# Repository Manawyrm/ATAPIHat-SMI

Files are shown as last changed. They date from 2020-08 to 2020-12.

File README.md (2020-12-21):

ATAPIHat-SMI
=============================

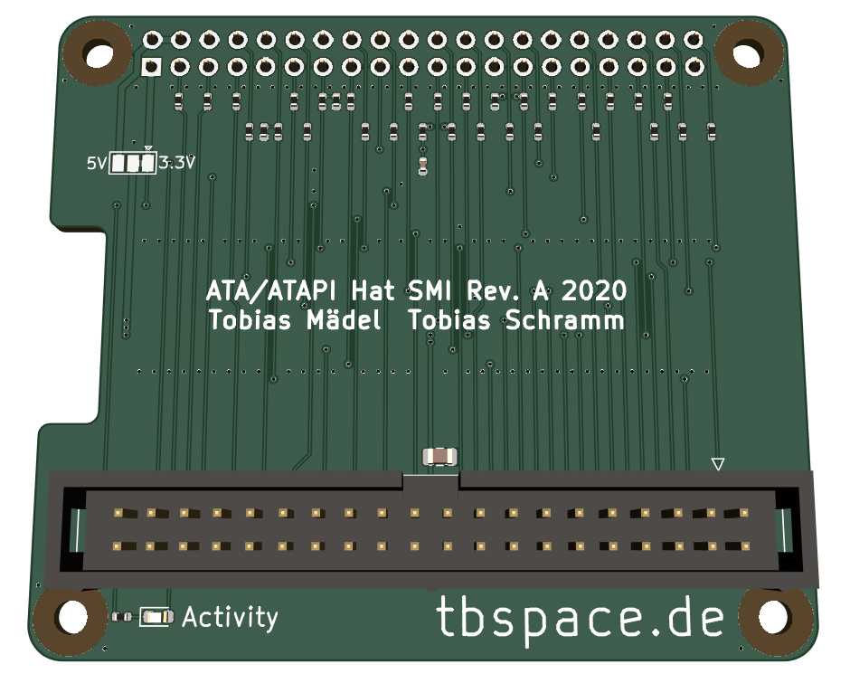
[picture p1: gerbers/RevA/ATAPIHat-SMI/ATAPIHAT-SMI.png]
Adapter PCB


### Overview

This is an experimental adapter PCB for the pata-gpio driver.  
The pinout was chosen deliberately to support faster SMI and BCM2835 register modes,  
which are not yet supported in the kernel driver. 

Rev.A testboards were ordered but not tested yet. **Proceed at your own risk.** 

### Manufacturing
Manufacturing files for [JLCPCBs](https://jlcpcb.com) automatic assembly service can be found at `gerbers/RevA/ATAPIHat-SMI/`.  
5 adapter boards cost ~15$ (incl. components). 

### Additional info 

[Schematic](gerbers/RevA/ATAPIHat-SMI/ATAPIHat-SMI.pdf)  
[Interactive BOM](https://tbspace.de/content/downloads/atapihat-smi-ibom-reva.html)  
[Bitbanged-GPIO Kernel driver](https://github.com/Manawyrm/pata-gpio)  

### Credits
The PCB layout was done by [@Toble_Miner](https://github.com/TobleMiner)! Thanks!

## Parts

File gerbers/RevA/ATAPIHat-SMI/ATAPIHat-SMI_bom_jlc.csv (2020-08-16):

Comment | Designator | Footprint | LCSC Part #
100nF | C1 | C_0402_1005Metric | C1525
22uF | C2 | C_0805_2012Metric | C45783
LED | D1 | LED_0603_1608Metric | C72043
4.7k | R3,R17 | R_0402_1005Metric | C25900
75R | R8,R7,R20 | R_0402_1005Metric | C25133
10k | R16,R18 | R_0402_1005Metric | C25744
5.6k | R19 | R_0402_1005Metric | C25908
22R | R23,R30,R14 | R_0402_1005Metric | C25092
33R | R24,R31,R25,R32,R26,R33,R9,R1,R2,R10,R11,R4,R12,R5,R13,R6,R29,R22,R28,R21,R15,R27 | R_0402_1005Metric | C25105

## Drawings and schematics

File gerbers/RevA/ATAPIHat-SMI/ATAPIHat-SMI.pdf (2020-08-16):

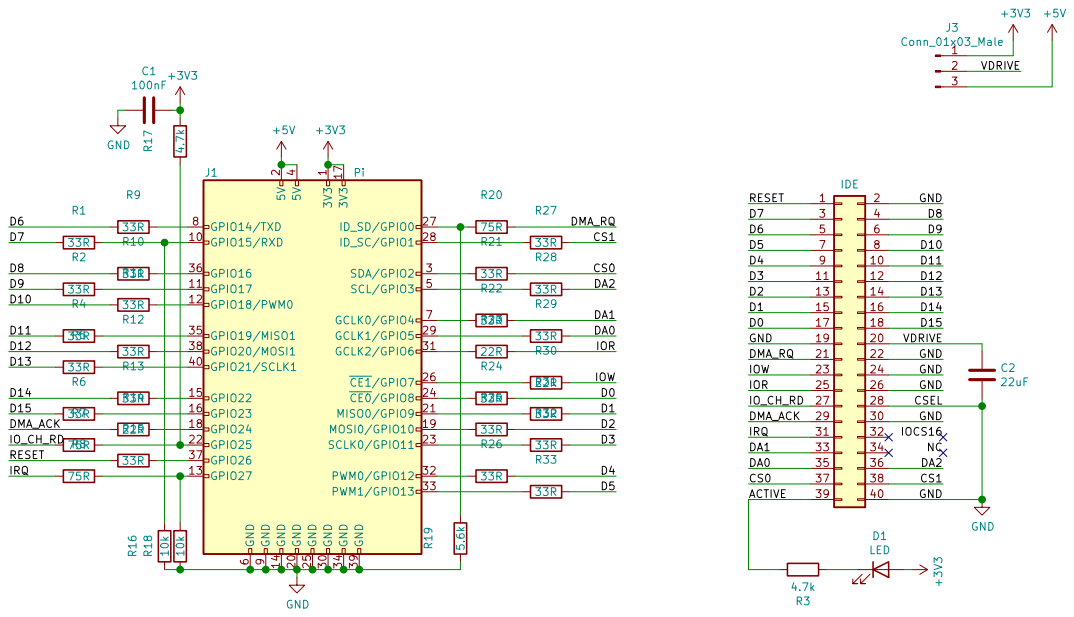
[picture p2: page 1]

D13 D14 GND GND GND GND

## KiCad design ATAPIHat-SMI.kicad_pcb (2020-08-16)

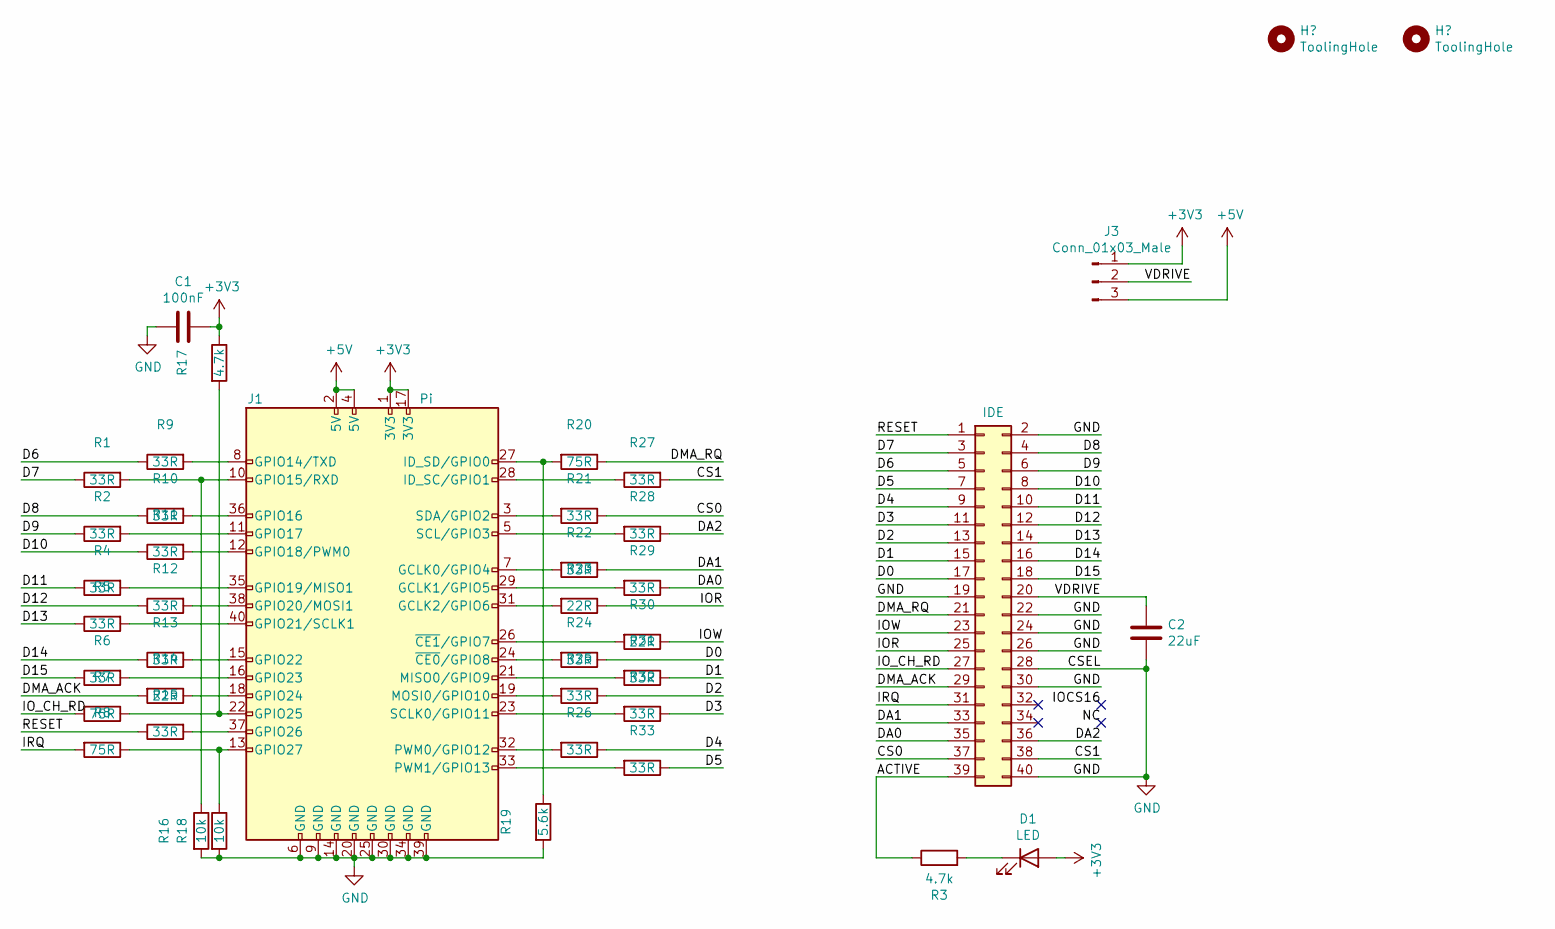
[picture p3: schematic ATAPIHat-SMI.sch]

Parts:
C1: 100nF; C_0402_1005Metric; LCSC C1525
C2: 22uF; C_0805_2012Metric; LCSC C45783
D1: LED; LED_0603_1608Metric; LCSC C72043
J1: Pi; PinSocket_2x20_P2.54mm_Vertical
J2: IDE; IDC-Header_2x20_P2.54mm_Vertical
J3: Conn_01x03_Male; SolderJumper-3_P1.3mm_Bridged12_Pad1.0x1.5mm
R1, R2, R4, R5, R6, R9, R10, R11, R12, R13, R15, R21, R22, R24, R25, R26, R27, R28, R29, R31, R32, R33: 33R; R_0402_1005Metric; LCSC C25105
R3, R17: 4.7k; R_0402_1005Metric; LCSC C25900
R7, R8, R20: 75R; R_0402_1005Metric; LCSC C25133
R14, R23, R30: 22R; R_0402_1005Metric; LCSC C25092
R16, R18: 10k; R_0402_1005Metric; LCSC C25744
R19: 5.6k; R_0402_1005Metric; LCSC C25908

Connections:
+3V3: C1.1, D1.2 (A), J1.1 (3V3), J1.17 (3V3), J3.1, R17.1
+5V: J1.2 (5V), J1.4 (5V), J3.3
/ACTIVE: J2.39, R3.1
/CS0: J2.37, R21.1
/CS1: J2.38, R27.2
/D0: J2.17, R24.1
/D1: J2.15, R31.1
/D2: J2.13, R25.1
/D3: J2.11, R32.1
/D4: J2.9, R26.1
/D5: J2.7, R33.1
/D6: J2.5, R9.1
/D7: J2.3, R1.1
/D8: J2.4, R10.1
/D9: J2.6, R2.1
/D10: J2.8, R11.1
/D11: J2.10, R4.1
/D12: J2.12, R12.1
/D13: J2.14, R5.1
/D14: J2.16, R13.1
/D15: J2.18, R6.1
/DA0: J2.35, R29.1
/DA1: J2.33, R22.1
/DA2: J2.36, R28.1
/DMA_ACK: J2.29, R14.2
/DMA_RQ: J2.21, R20.1
/IOR: J2.25, R23.1
/IOW: J2.23, R30.1
/IO_CH_RD: J2.27, R7.2
/IRQ: J2.31, R8.2
/RESET: J2.1, R15.1
/VDRIVE: C2.1, J2.20, J3.2
GND: C1.2, C2.2, J1.6 (GND), J1.9 (GND), J1.14 (GND), J1.20 (GND), J1.25 (GND), J1.30 (GND), J1.34 (GND), J1.39 (GND), J2.2, J2.19, J2.22, J2.24, J2.26, J2.28, J2.30, J2.40, R16.2, R18.2, R19.2
unnamed: D1.1 (K), R3.2
unnamed: J1.3 (SDA/GPIO2), R21.2
unnamed: J1.5 (SCL/GPIO3), R28.2
unnamed: J1.7 (GCLK0/GPIO4), R22.2
unnamed: J1.8 (GPIO14/TXD), R9.2
unnamed: J1.10 (GPIO15/RXD), R1.2, R16.1
unnamed: J1.11 (GPIO17), R2.2
unnamed: J1.12 (GPIO18/PWM0), R11.2
unnamed: J1.13 (GPIO27), R8.1, R18.1
unnamed: J1.15 (GPIO22), R13.2
unnamed: J1.16 (GPIO23), R6.2
unnamed: J1.18 (GPIO24), R14.1
unnamed: J1.19 (MOSI0/GPIO10), R25.2
unnamed: J1.21 (MISO0/GPIO9), R31.2
unnamed: J1.22 (GPIO25), R7.1, R17.2
unnamed: J1.23 (SCLK0/GPIO11), R32.2
unnamed: J1.24 (~CE0~/GPIO8), R24.2
unnamed: J1.26 (~CE1~/GPIO7), R30.2
unnamed: J1.27 (ID_SD/GPIO0), R19.1, R20.2
unnamed: J1.28 (ID_SC/GPIO1), R27.1
unnamed: J1.29 (GCLK1/GPIO5), R29.2
unnamed: J1.31 (GCLK2/GPIO6), R23.2
unnamed: J1.32 (PWM0/GPIO12), R26.2
unnamed: J1.33 (PWM1/GPIO13), R33.2
unnamed: J1.35 (GPIO19/MISO1), R4.2
unnamed: J1.36 (GPIO16), R10.2
unnamed: J1.37 (GPIO26), R15.2
unnamed: J1.38 (GPIO20/MOSI1), R12.2
unnamed: J1.40 (GPIO21/SCLK1), R5.2

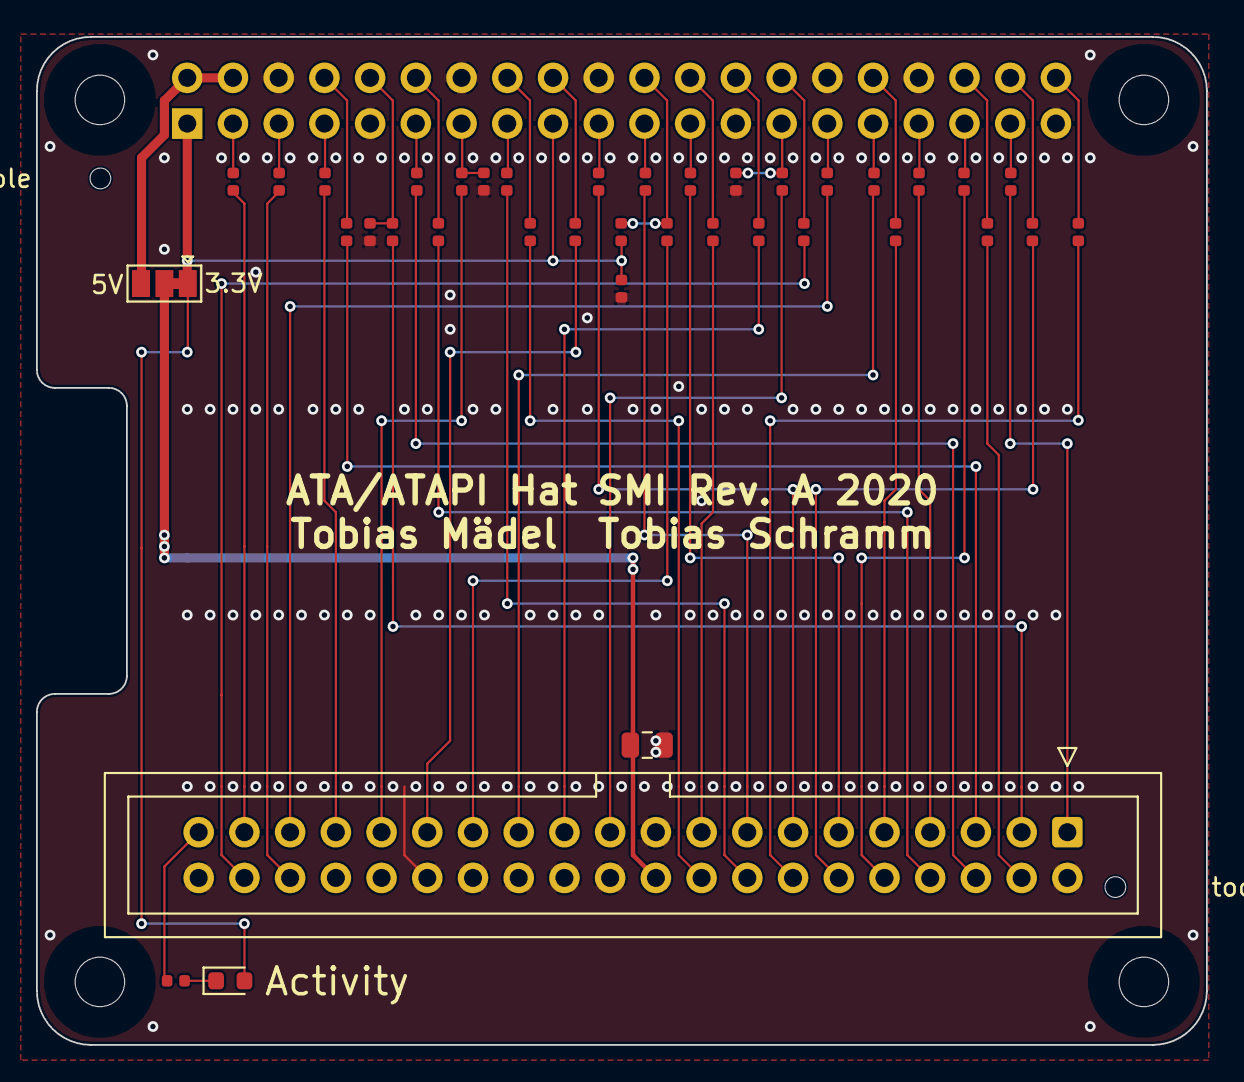
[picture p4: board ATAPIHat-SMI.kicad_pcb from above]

Board: 2 copper layers, 65.0 x 56.0 mm, 41 parts (1 on the bottom side), 62 nets.

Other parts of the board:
H1, H2: ToolingHole; ToolingHole_JLCSMT

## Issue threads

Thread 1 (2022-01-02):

Schematic ATAPIHat-SMI.pdf displays incorrectly

fonic, 2022-01-02:
The schematic [ATAPIHat-SMI.pdf](https://github.com/Manawyrm/ATAPIHat-SMI/blob/master/gerbers/RevA/ATAPIHat-SMI/ATAPIHat-SMI.pdf) displays incorrectly, see e.g. resistors of lines D8 and D11:

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

I tried several different PDF viewers (including Adobe Acrobat DC), but I couldn't get it to display correctly, thus I assume there is something wrong with the PDF file itself.

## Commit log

2020-08-08 Add initial schematic
    [ATAPIHat-SMI.kicad_pcb, ATAPIHat-SMI.sch]
2020-08-09 Correct cable select
    [ATAPIHat-SMI.sch]
2020-08-09 Do layout
    [ATAPIHat-SMI.kicad_pcb, ATAPIHat-SMI.sch]
2020-08-09 Center hat name
    [ATAPIHat-SMI.kicad_pcb]
2020-08-12 Add gerber, manufacturing files and README
    [ATAPIHat-SMI-B_Cu.gbl, ATAPIHat-SMI-B_Mask.gbs, ATAPIHat-SMI-B_Paste.gbp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]
2020-08-16 Add tooling holes
    [ATAPIHat-SMI.kicad_pcb, ATAPIHat-SMI.sch]
